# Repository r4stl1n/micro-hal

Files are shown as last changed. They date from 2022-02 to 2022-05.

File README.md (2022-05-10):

# Micro Hal - Spot Micro bot Variation

Notice: The current GO rewrite is paused while we iron out the hardware and electornic selection and support.
For the time being ros-noetic will be used. Please check the ros-rework branch.

This take on the spot-micro attempts to pull pieces together from various different spot projects into one complete package.

The goal of this project is to not only pull the best pieces from the various spot projects but also to have a single repo that contains everything you need to get up and running smoothly.

Each project that pieces are taken from will be documented in this README so anyone who is interested can visit the parent projects.

All current code samples, models, and rewrites used for this project will be posted within this repo.

Note: This is a in-progress working spot micro bot written in GO

## Project Structure

Due to the amount of different data involved the project will be stored in various directories. This goes as follows:

```bash
micro-hal
├── code                       - Code repository for working with micro hal
│   ├── cmd                    - Micro hal Applications
│   │    └── hal-utilities     - Utility Application
│   │
├── parts                      - Parts Necessary
│    └── 3d-prints             
│       ├── freecad            - Original Free Cad Files
│       └── stl                - 3d Printable STL Files
│           └── templates      - Template STLS to modify for different hardware
│
└── sim                        - Sim folder containing everything required to run in gazebo
    ├── meshes                 
    │   └── stl                - STL files used to render the bot in gazebo
    ├── plugin                 - Gazebo plugin source directory
    │   └── include
    ├── urdf                   - The urdf and xacro file for the micro-hal bot
    └── world                  - Folder containing the world defenition file for gazebo

```

## Reference && Community

Deok-Yeon Kim (KDY0523) - Original design of the sport micro: https://www.thingiverse.com/thing:3445283

Michael Kubina (michaelkubina) - Easy print redesign of the spot micro: https://github.com/michaelkubina/SpotMicroESP32/

CHVMP - Original quad kinematics and node code - https://github.com/chvmp/champ

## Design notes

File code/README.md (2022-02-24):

# Code

This is the central area for code that is used to work with and to control the Micro-Hal bot.
Below is a break down of the current features and components that work within the micro-hal framework.

TODO: Fill in the NATS/MSGPack based singaling 

## Requirements

The solution uses a make file to build the project and to ensure code formatting and checking.

StaticCheck will need to be installed this can be done by calling

```bash
go install honnef.co/go/tools/cmd/staticcheck@latest
```

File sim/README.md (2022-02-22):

# Sim

This folder contains everything needed to run micro-hal in simulation using gazebo.

TODO: Fill this out alot better

## Setup

Below are the rough steps for getting the simulation running

### Building the micro-hal plugin
In order for our simulation to work and be able to communicate with the micro-hal stack we first have to build our plugin so it can work.
Aside from needing the gazebo-dev libraries we will also needs a nats and msgpack library

TODO: Add the lib names here for debian

To build the project simply do the following.

```bash
cd plugin
mkdir build
cd build
cmake ../
make
```

### Exporting the plugin path

In order for gazebo to be able to find our plugin we need to export the plugin location. In a terminal do the following

```bash
export GAZEBO_PLUGIN_PATH=${GAZEBO_PLUGIN_PATH}:<Full Path to the cmake-build-debug>
```

### GZServer
To start the gzserver context with our selected world do the following.

```bash
export GAZEBO_PLUGIN_PATH=${GAZEBO_PLUGIN_PATH}:<Full Path to the cmake-build-debug>
gzserver world/hal.world --verbose
```

### GZClient
To start the client run the following

```bash
export GAZEBO_PLUGIN_PATH=${GAZEBO_PLUGIN_PATH}:<Full Path to the cmake-build-debug>
gzclient --verbose

```

### Spawn robot
Finally all that is left is to spawn our robot. Gazebo can load a urdf file directly so no need to convert it over to a sdf

```bash
export GAZEBO_PLUGIN_PATH=${GAZEBO_PLUGIN_PATH}:<Full Path to the cmake-build-debug>
gz model --spawn-file=./urdf/micro-hal.urdf --model-name=micro-hal
```

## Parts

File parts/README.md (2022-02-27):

# Parts

Here are the things you will need to purchase in order to build the bot the same way that is described in this repo. 
The table here will all be amazon (none affiliate) links however feel free to source the parts from wherever you want.
Going to assume you have all the side things need (Soldering Iron, Flux, Printer Filament, Wires,Etc) 

Note: The amount specifies how many of a single component you need. Ex. the Ultrasonic sensors ship in packs of 5. We only need 2 of those 5 for the build.

If you are looking for the 3d Printed Parts just navigate to the 3d-prints folder.

## The Damage

While the spot micro bots are "affordable" compared to the real spot bot they are still costly. With just whats listed here the total is the following.

Total: **$447**

This does not include filament, wires, or anything else.

## Electronics

The electronics necessary in order to build the hal bot

| Name |Usage | Amount | Cost | Link |
|---| ---| ---|---|---|
| Raspberry Pi 4 B 8GB | Processing | 1  | $55 | [Link](https://www.adafruit.com/product/4296) |
| 19m 12V Push Button | On/Off Button | 1  | $17 | [Link](https://www.amazon.com/dp/B08225LGRT) | 
| 200W 15A DC-DC Power Supply | Voltage Regulator (Servo) | 1  | $15 | [Link](https://www.amazon.com/dp/B072BN43P8) | 
| DS3218MG 20KG Digital Servo High | Leg Movement | 12 | $204| [Link](https://www.amazon.com/dp/B076CNKQX4) |
| PCA9685 16 Channel PWM Server Driver  | Servo Control | 1  | $10 | [Link](https://www.amazon.com/dp/B014KTSMLA) |
| SSD1306 Driver I2C Display | Status Display | 1  | $7  | [Link](https://www.amazon.com/dp/B072Q2X2LL) |
| Zeee 7.4V 2S 5200mAh Lipo Battery 50C | Power Source | 1  | $35 | [Link](https://www.amazon.com/dp/B08DD38XKV) |
| LSM6DS3 Module 6 degress IMU | Orientation / Balance | 1  | $9  | [Link](https://www.amazon.com/dp/B091TPT3TJ) |
| HC-SR04 Ultrasonic Sensor Module | Collision Avoidance | 2  | $8  | [Link](https://www.amazon.com/dp/B07R7RMXTY) |
| iFlight Mirco BEC 5V 3A / 12V 2A | Voltage Regulator (RPi) | 1  | $15 | [Link](https://www.amazon.com/dp/B0823QLMWC) | 
| Servo Extension Cord Cable | Extend Servo Wires | 12 | $8  | [Link](https://www.amazon.com/dp/B01LA9YDEI) |

## Hardware

The hardware necessary to put it all together

| Name | Amount | Cost | Link |
|---| ---| ---|---|
| 625ZZ Bearing | 8 | $11 | [Link](https://www.amazon.com/dp/B081YRKRNS) |
| M2x0.4mm Hex Nuts | 84  | $9  | [Link](https://www.amazon.com/dp/B07H3SXSN2) |
| M2x8 Socket Hex Pan | 84  | $9  | [Link](https://www.amazon.com/dp/B01EZPNXZO) |
| M3 Carbon Steel Hex Nuts | 144 | $14 | [Link](https://www.amazon.com/dp/B07H3SXSN2) |
| M3 x 8mm Socket Head Cap Screws | 80  | $9  | [Link](https://www.amazon.com/dp/B07NTG92SL) |
| M3x20mm Screw Cap Point Hex | 64  | $11 | [Link](https://www.amazon.com/dp/B0143GZHDG) |

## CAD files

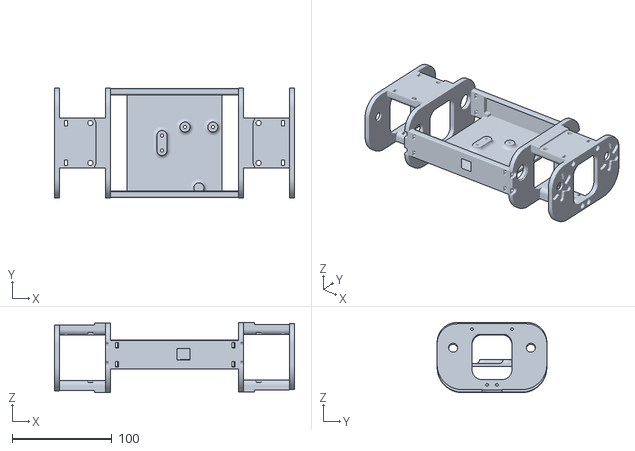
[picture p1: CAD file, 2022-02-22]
sim/meshes/stl/mainbody.stl
240.7 x 110.0 x 70.4

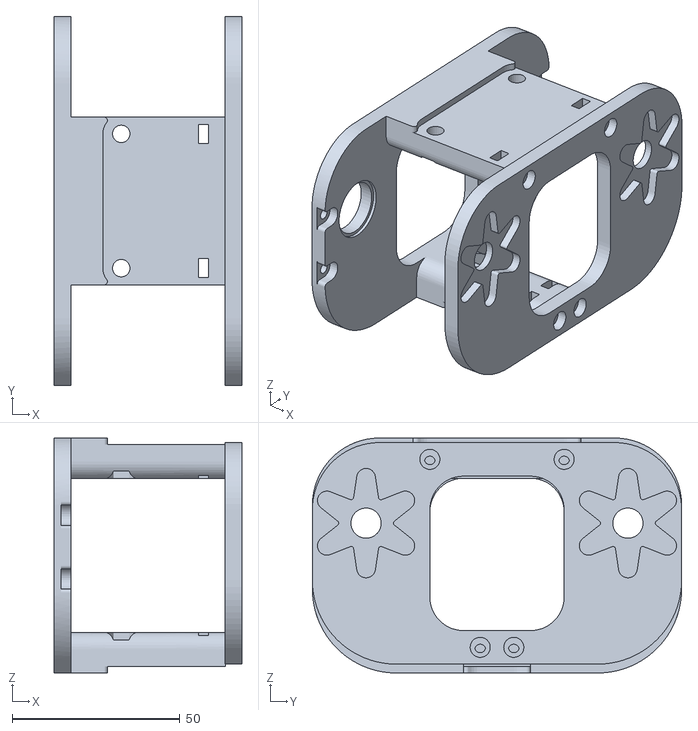
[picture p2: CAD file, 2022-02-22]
sim/meshes/stl/rearmain.stl
55.9 x 110.0 x 70.0

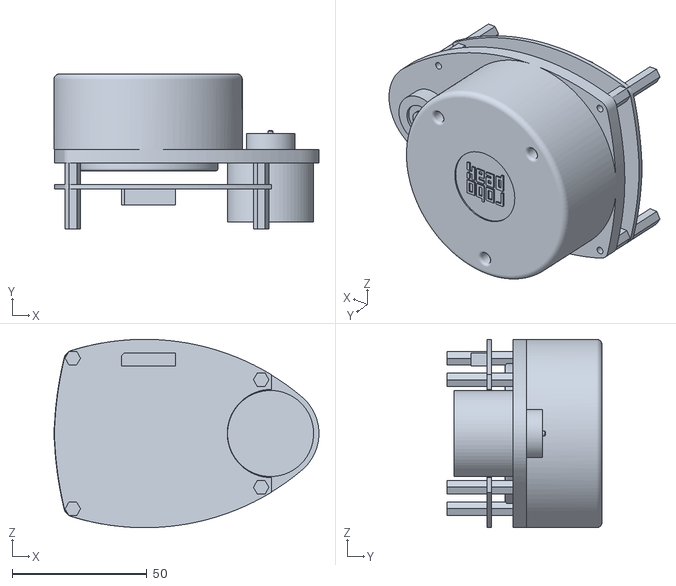
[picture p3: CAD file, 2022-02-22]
sim/meshes/stl/rplidar_main.STL
98.5 x 57.7 x 70.0

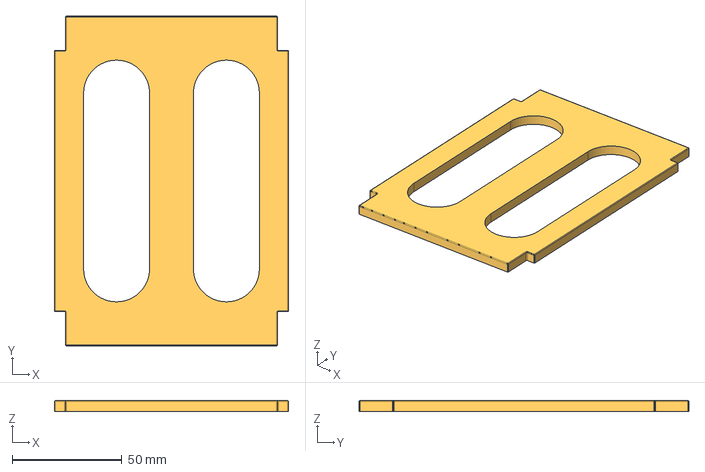
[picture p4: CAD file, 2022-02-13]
parts/3d-prints/freecad/Circuitboard_Mount (Template).FCStd
106.5 x 150.0 x 5.00 mm

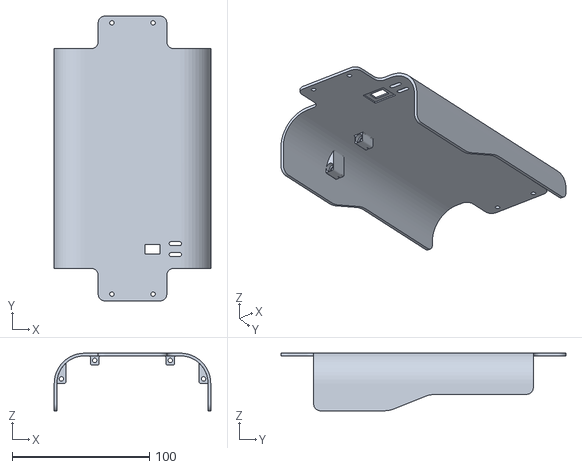
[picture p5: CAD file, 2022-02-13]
parts/3d-prints/stl/templates/Top_Cover (Template).stl
114.0 x 207.5 x 42.0

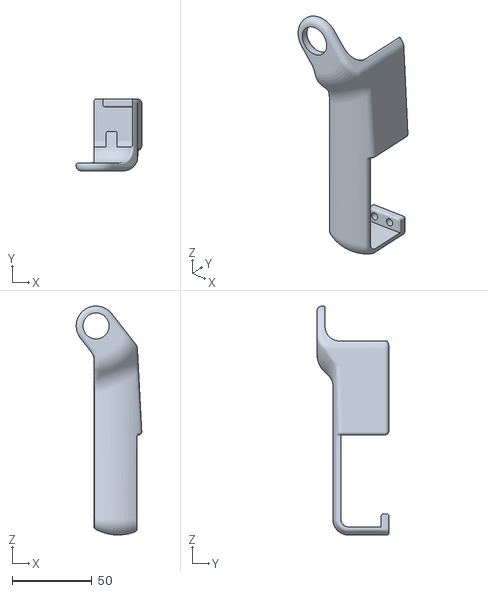
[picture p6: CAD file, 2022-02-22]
sim/meshes/stl/R_arm_cover.stl
41.2 x 45.0 x 143.5

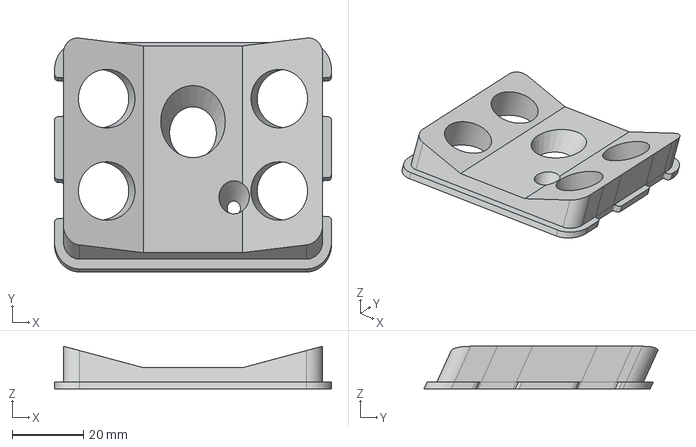
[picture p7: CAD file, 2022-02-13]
parts/3d-prints/freecad/sensormount_esp32_cam.FCStd
78.0 x 65.9 x 12.0 mm

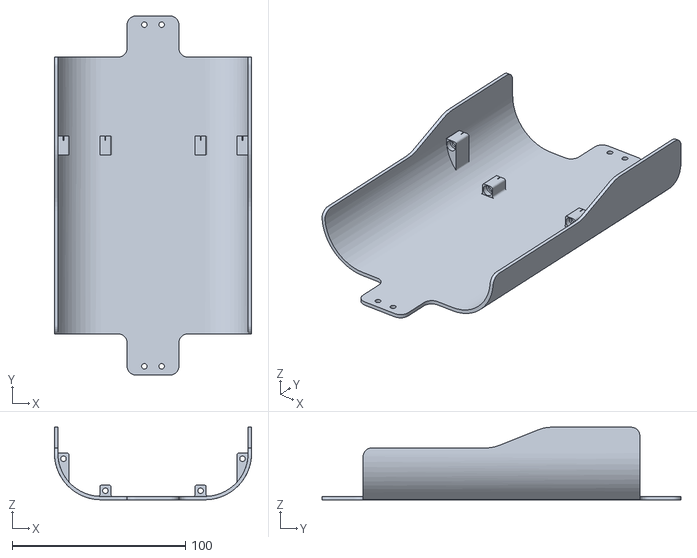
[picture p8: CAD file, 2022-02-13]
parts/3d-prints/stl/templates/Bottom_Cover (Template).stl
114.0 x 207.5 x 42.0

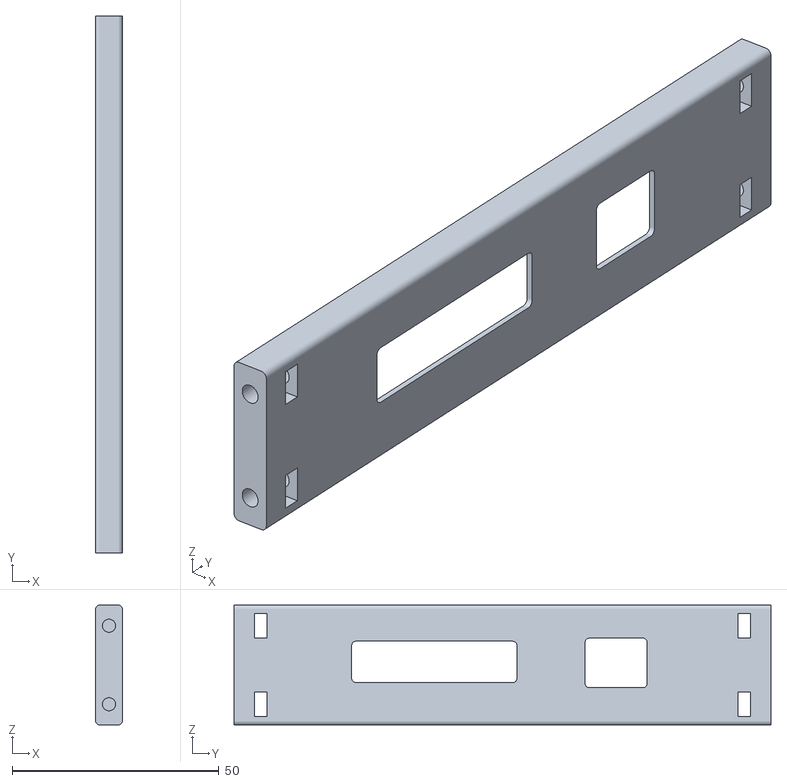
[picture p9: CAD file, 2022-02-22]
sim/meshes/stl/jetson_sidepart.stl
6.50 x 130.0 x 29.0

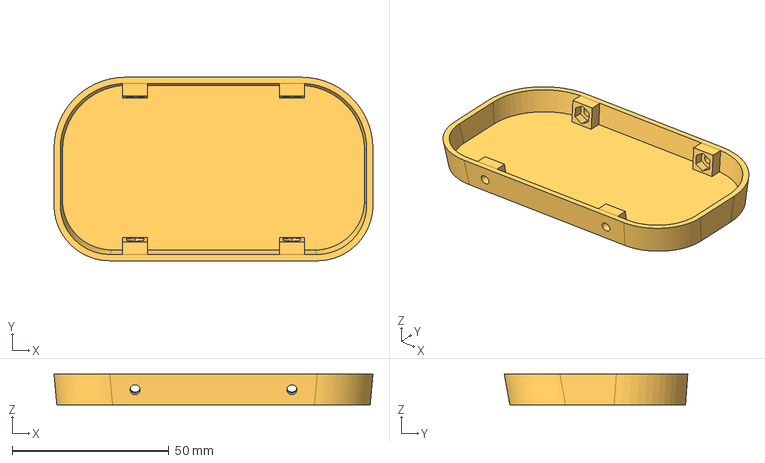
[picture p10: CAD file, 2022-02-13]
parts/3d-prints/freecad/Rear_Cover_Plate_Template.FCStd
101.7 x 58.5 x 9.75 mm

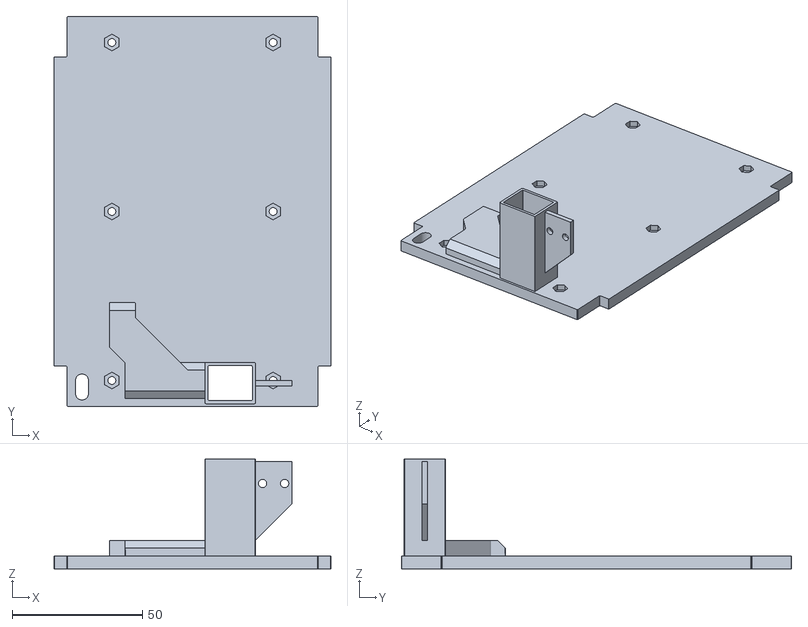
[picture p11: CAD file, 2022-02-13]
parts/3d-prints/stl/templates/Circuitry_Mountingplate (Template).stl
106.5 x 150.0 x 42.2

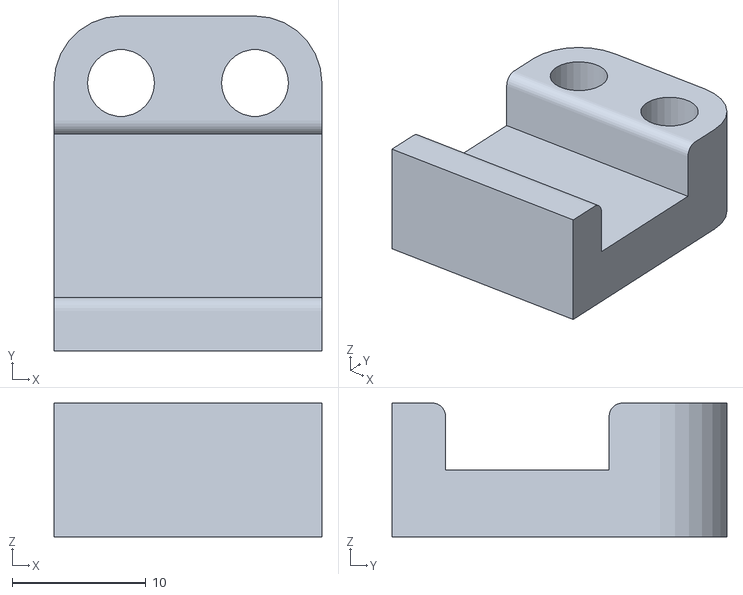
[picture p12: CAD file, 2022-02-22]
sim/meshes/stl/testmount.stl
20.0 x 25.0 x 10.0

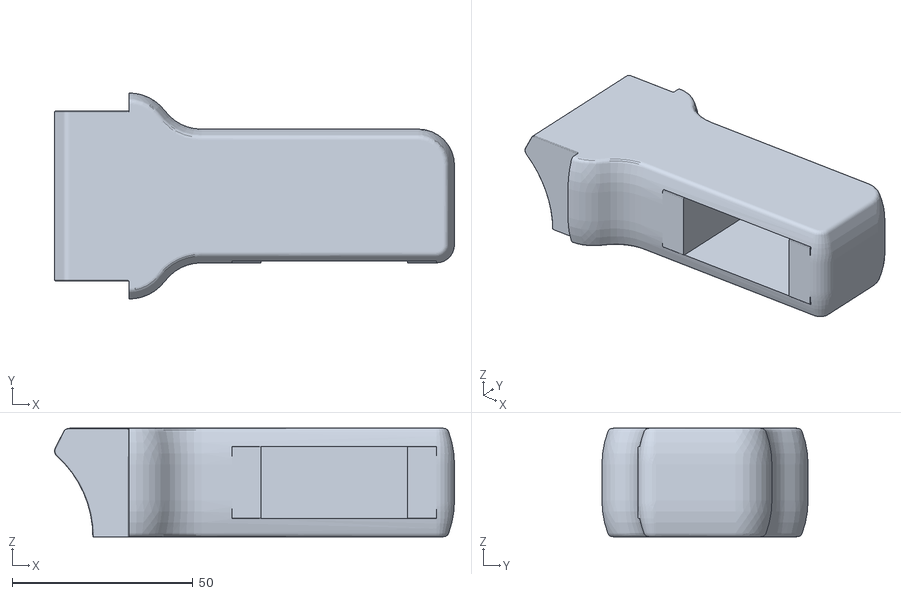
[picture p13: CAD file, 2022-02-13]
parts/3d-prints/stl/templates/Limb_Basebody (Template).stl
110.6 x 57.0 x 30.0

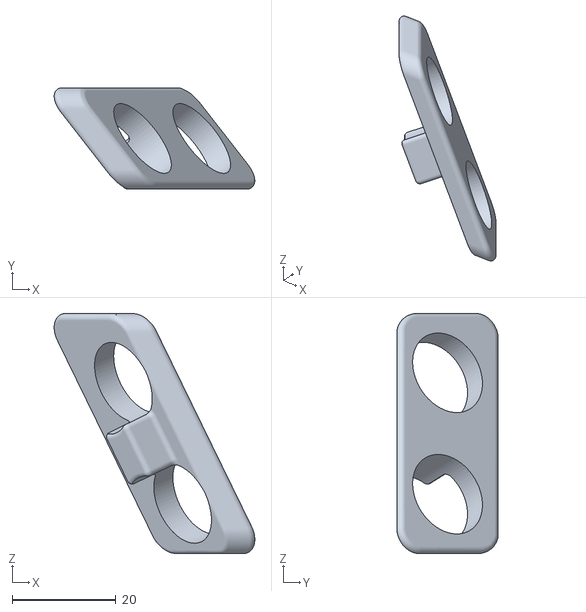
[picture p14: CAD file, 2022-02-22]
sim/meshes/stl/L_ultra_sonic.stl
38.6 x 19.5 x 46.2

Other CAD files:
parts/3d-prints/freecad/Sensormount.FCStd
parts/3d-prints/freecad/Front_Cover.FCStd
parts/3d-prints/stl/templates/Rear_Cover (Template).stl
sim/meshes/stl/ledholder.stl
parts/3d-prints/freecad/Bottom_Cover (Template).FCStd
parts/3d-prints/freecad/Bottom_Cover_Split_Front.FCStd
parts/3d-prints/freecad/Bottom_Cover_Split_Rear.FCStd
parts/3d-prints/freecad/Bottom_Shoulder.FCStd
parts/3d-prints/freecad/Cameramount.FCStd
parts/3d-prints/freecad/Chassis_Side.FCStd
parts/3d-prints/freecad/Circuitry_Mountingplate (Template).FCStd
parts/3d-prints/freecad/Circuitry_Mountingplate.FCStd
parts/3d-prints/freecad/Circuitry_Mountingplate_Extended.FCStd
parts/3d-prints/freecad/Circuitry_Mountingplate_SZBK07.FCStd
parts/3d-prints/freecad/Circuitry_Mountingplate_SZBK07_Extended.FCStd
parts/3d-prints/freecad/Foot_Tip.FCStd
parts/3d-prints/freecad/Front_Cover_Optimized.FCStd
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

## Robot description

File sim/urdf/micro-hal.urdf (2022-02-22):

<?xml version="1.0" encoding="utf-8"?>
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
<robot name="Micro-Hal">
  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
  <link name="base_link"/>
  <link name="base_inertia">
    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
    <inertial>
      <mass value="2.80"/>
      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
    </inertial>
  </link>
  <joint name="base_inertia_joint" type="fixed">
    <parent link="base_link"/>
    <child link="base_inertia"/>
  </joint>
  <link name="rear_link">
    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
    <inertial>
      <mass value="0.20"/>
      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
    </inertial>
  </link>
  <joint name="base_rear" type="fixed">
    <parent link="base_link"/>
    <child link="rear_link"/>
  </joint>
  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
  <link name="front_link">
    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
    <inertial>
      <mass value="0.20"/>
      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
    </inertial>
  </link>
  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
  <joint name="base_front" type="fixed">
    <parent link="base_link"/>
    <child link="front_link"/>
  </joint>
  <link name="front_left_shoulder_link">
    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
    <inertial>
      <mass value="0.10"/>
      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
    </inertial>
  </link>
  <link name="front_left_leg_link_cover">
    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
  </link>
  <link name="front_left_leg_link">
    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
    <inertial>
      <mass value="0.15"/>
      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
    </inertial>
  </link>
  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
  <link name="front_left_foot_link">
    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
    <inertial>
      <mass value="0.1"/>
      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
    </inertial>
  </link>
  <link name="front_left_toe_link">
    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
    <inertial>
      <mass value="0.05"/>
      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
    </inertial>
  </link>
  <joint name="front_left_shoulder" type="revolute">
    <parent link="base_link"/>
    <child link="front_left_shoulder_link"/>
    <axis xyz="1 0 0"/>
    <origin rpy="0 0 0" xyz="0.093 0.0395 0"/>
    <limit effort="1000.0" lower="-0.548" upper="0.548" velocity="0.7"/>
    <dynamics damping="0.0" friction="0.5"/>
  </joint>
  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
  <joint name="front_left_leg" type="revolute">
    <parent link="front_left_shoulder_link"/>
    <child link="front_left_leg_link"/>
    <axis xyz="0 1 0"/>
    <origin rpy="0 0 0" xyz="0 0.055 0"/>
    <limit effort="1000.0" lower="-2.666" upper="1.548" velocity="0.5"/>
    <dynamics damping="0.0" friction="0.0"/>
  </joint>
  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
  <joint name="front_left_leg_cover_joint" type="fixed">
    <parent link="front_left_leg_link"/>
    <child link="front_left_leg_link_cover"/>
    <origin xyz="0 0 0"/>
  </joint>
  <joint name="front_left_foot" type="revolute">
    <parent link="front_left_leg_link"/>
    <child link="front_left_foot_link"/>
    <axis xyz="0 1 0"/>
    <origin rpy="0 0 0" xyz="0.014 0 -0.109"/>
    <limit effort="1000.0" lower="-2.59" upper="0.1" velocity="0.5"/>
    <dynamics damping="0.0" friction="0.5"/>
  </joint>
  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
  <joint name="front_left_toe" type="fixed">
    <parent link="front_left_foot_link"/>
    <child link="front_left_toe_link"/>
    <origin xyz="0 0 -0.13"/>
  </joint>
  <link name="front_right_shoulder_link">
    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
    <inertial>
      <mass value="0.10"/>
      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
    </inertial>
  </link>
  <link name="front_right_leg_link_cover">
    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
  </link>
  <link name="front_right_leg_link">
    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
    <inertial>
      <mass value="0.15"/>
      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
    </inertial>
  </link>
  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
  <link name="front_right_foot_link">
    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
    <inertial>
      <mass value="0.1"/>
      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
    </inertial>
  </link>
  <link name="front_right_toe_link">
    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
    <inertial>
      <mass value="0.05"/>
      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
    </inertial>
  </link>
  <joint name="front_right_shoulder" type="revolute">
    <parent link="base_link"/>
    <child link="front_right_shoulder_link"/>
    <axis xyz="1 0 0"/>
    <origin rpy="0 0 0" xyz="0.093 -0.0395 0"/>
    <limit effort="1000.0" lower="-0.548" upper="0.548" velocity="0.7"/>
    <dynamics damping="0.0" friction="0.5"/>
  </joint>
  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
  <joint name="front_right_leg" type="revolute">
    <parent link="front_right_shoulder_link"/>
    <child link="front_right_leg_link"/>
    <axis xyz="0 1 0"/>
    <origin rpy="0 0 0" xyz="0 -0.055 0"/>
    <limit effort="1000.0" lower="-2.666" upper="1.548" velocity="0.5"/>
    <dynamics damping="0.0" friction="0.0"/>
  </joint>
  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
  <joint name="front_right_leg_cover_joint" type="fixed">
    <parent link="front_right_leg_link"/>
    <child link="front_right_leg_link_cover"/>
    <origin xyz="0 0 0"/>
  </joint>
  <joint name="front_right_foot" type="revolute">
    <parent link="front_right_leg_link"/>
    <child link="front_right_foot_link"/>
    <axis xyz="0 1 0"/>
    <origin rpy="0 0 0" xyz="0.014 0 -0.109"/>
    <limit effort="1000.0" lower="-2.59" upper="0.1" velocity="0.5"/>
    <dynamics damping="0.0" friction="0.5"/>
  </joint>
  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
  <joint name="front_right_toe" type="fixed">
    <parent link="front_right_foot_link"/>
    <child link="front_right_toe_link"/>
    <origin xyz="0 0 -0.13"/>
  </joint>
  <link name="rear_left_shoulder_link">
    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
    <inertial>
      <mass value="0.10"/>
      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
    </inertial>
  </link>
  <link name="rear_left_leg_link_cover">
    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
  </link>
  <link name="rear_left_leg_link">
    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
    <inertial>
      <mass value="0.15"/>
      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
    </inertial>
  </link>
  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
  <link name="rear_left_foot_link">
    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
    <inertial>
      <mass value="0.1"/>
      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
    </inertial>
  </link>
  <link name="rear_left_toe_link">
    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
    <inertial>
      <mass value="0.05"/>
      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
    </inertial>
  </link>
  <joint name="rear_left_shoulder" type="revolute">
    <parent link="base_link"/>
    <child link="rear_left_shoulder_link"/>
    <axis xyz="1 0 0"/>
    <origin rpy="0 0 0" xyz="-0.093 0.0395 0"/>
    <limit effort="1000.0" lower="-0.548" upper="0.548" velocity="0.7"/>
    <dynamics damping="0.0" friction="0.5"/>
  </joint>
  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
  <joint name="rear_left_leg" type="revolute">
    <parent link="rear_left_shoulder_link"/>
    <child link="rear_left_leg_link"/>
    <axis xyz="0 1 0"/>
    <origin rpy="0 0 0" xyz="0 0.055 0"/>
    <limit effort="1000.0" lower="-2.666" upper="1.548" velocity="0.5"/>
    <dynamics damping="0.0" friction="0.0"/>
  </joint>
  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
  <joint name="rear_left_leg_cover_joint" type="fixed">
    <parent link="rear_left_leg_link"/>
    <child link="rear_left_leg_link_cover"/>
    <origin xyz="0 0 0"/>
  </joint>
  <joint name="rear_left_foot" type="revolute">
    <parent link="rear_left_leg_link"/>
    <child link="rear_left_foot_link"/>
    <axis xyz="0 1 0"/>
    <origin rpy="0 0 0" xyz="0.014 0 -0.109"/>
    <limit effort="1000.0" lower="-2.59" upper="0.1" velocity="0.5"/>
    <dynamics damping="0.0" friction="0.5"/>
  </joint>
  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
  <joint name="rear_left_toe" type="fixed">
    <parent link="rear_left_foot_link"/>
    <child link="rear_left_toe_link"/>
    <origin xyz="0 0 -0.13"/>
  </joint>
  <link name="rear_right_shoulder_link">
    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
    <inertial>
      <mass value="0.10"/>
      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
    </inertial>
  </link>
  <link name="rear_right_leg_link_cover">
    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
  </link>
  <link name="rear_right_leg_link">
    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
    <inertial>
      <mass value="0.15"/>
      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
    </inertial>
  </link>
  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
  <link name="rear_right_foot_link">
    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
    <inertial>
      <mass value="0.1"/>
      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
    </inertial>
  </link>
  <link name="rear_right_toe_link">
    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
    <inertial>
      <mass value="0.05"/>
      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
    </inertial>
  </link>
  <joint name="rear_right_shoulder" type="revolute">
    <parent link="base_link"/>
    <child link="rear_right_shoulder_link"/>
    <axis xyz="1 0 0"/>
    <origin rpy="0 0 0" xyz="-0.093 -0.0395 0"/>
    <limit effort="1000.0" lower="-0.548" upper="0.548" velocity="0.7"/>
    <dynamics damping="0.0" friction="0.5"/>
  </joint>
  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
  <joint name="rear_right_leg" type="revolute">
    <parent link="rear_right_shoulder_link"/>
    <child link="rear_right_leg_link"/>
    <axis xyz="0 1 0"/>
    <origin rpy="0 0 0" xyz="0 -0.055 0"/>
    <limit effort="1000.0" lower="-2.666" upper="1.548" velocity="0.5"/>
    <dynamics damping="0.0" friction="0.0"/>
  </joint>
  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
  <joint name="rear_right_leg_cover_joint" type="fixed">
    <parent link="rear_right_leg_link"/>
    <child link="rear_right_leg_link_cover"/>
    <origin xyz="0 0 0"/>
  </joint>
  <joint name="rear_right_foot" type="revolute">
    <parent link="rear_right_leg_link"/>
    <child link="rear_right_foot_link"/>
    <axis xyz="0 1 0"/>
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

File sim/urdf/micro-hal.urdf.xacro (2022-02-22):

<?xml version="1.0" encoding="UTF-8"?>
<robot xmlns:xacro="http://www.ros.org/wiki/xacro" name="Micro-Hal">
   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
   <xacro:property name="body_length" value="0.140" />
   <xacro:property name="body_width" value="0.110" />
   <xacro:property name="body_height" value="0.070" />
   <xacro:property name="lidar_length" value="0.0985" />
   <xacro:property name="lidar_width" value="0.0577" />
   <xacro:property name="lidar_height" value="0.070" />
   <xacro:property name="front_length" value="0.058" />
   <xacro:property name="rear_length" value="0.040" />
   <xacro:property name="shoulder_length" value="0.044" />
   <xacro:property name="shoulder_width" value="0.038" />
   <xacro:property name="leg_length" value="0.109" />
   <xacro:property name="foot_length" value="0.13" />
   <xacro:property name="toe_radius" value="0.020" />
   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
   <xacro:property name="toe_width" value="0.020" />
   <xacro:property name="shift" value="0.055" />
   <xacro:property name="shiftx" value="0.093" />
   <xacro:property name="shifty" value="0.0395" />
   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
   <xacro:macro name="gen_shoulder" params="name left">
      <link name="${name}">
         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
         <inertial>
            <mass value="0.10" />
            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
         </inertial>
      </link>
   </xacro:macro>
   <xacro:macro name="gen_shoulder_joint" params="pos shiftx shifty">
      <joint name="${pos}_shoulder" type="revolute">
         <parent link="base_link" />
         <child link="${pos}_shoulder_link" />
         <axis xyz="1 0 0" />
         <origin rpy="0 0 0" xyz="${shiftx} ${shifty} 0" />
         <limit effort="1000.0" velocity="0.7" lower="-0.548" upper="0.548"/>
         <dynamics damping="0.0" friction="0.5" />
      </joint>
      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
   </xacro:macro>
   <xacro:macro name="gen_leg" params="name left">
      <link name="${name}_cover">
         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
      </link>
      <link name="${name}">
         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
         <inertial>
            <mass value="0.15" />
            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
         </inertial>
      </link>
      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
   </xacro:macro>
   <xacro:macro name="gen_leg_joint" params="pos shift">
      <joint name="${pos}_leg" type="revolute">
         <parent link="${pos}_shoulder_link" />
         <child link="${pos}_leg_link" />
         <axis xyz="0 1 0" />
         <origin rpy="0 0 0" xyz="0 ${shift} 0" />
         <limit effort="1000.0" velocity="0.5" lower="-2.666" upper="1.548"/>
         <dynamics damping="0.0" friction="0.0" />
      </joint>
      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
      <joint name="${pos}_leg_cover_joint" type="fixed">
         <parent link="${pos}_leg_link" />
         <child link="${pos}_leg_link_cover" />
         <origin xyz="0 0 0" />
      </joint>
   </xacro:macro>
   <xacro:macro name="gen_foot" params="name left">
      <link name="${name}">
         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
         <inertial>
            <mass value="0.1" />
            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
         </inertial>
      </link>
   </xacro:macro>
   <xacro:macro name="gen_foot_joint" params="pos">
      <joint name="${pos}_foot" type="revolute">
         <parent link="${pos}_leg_link" />
         <child link="${pos}_foot_link" />
         <axis xyz="0 1 0" />
         <origin rpy="0 0 0" xyz="0.014 0 -${leg_length}" />
         <limit effort="1000.0" velocity="0.5" lower="-2.59" upper="0.1"/>
         <dynamics damping="0.0" friction="0.5" />
      </joint>
      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
   </xacro:macro>
   <xacro:macro name="gen_toe" params="name">
      <link name="${name}">
         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
         <inertial>
            <mass value="0.05" />
            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
         </inertial>
      </link>
   </xacro:macro>
   <xacro:macro name="gen_toe_joint" params="pos">
      <joint name="${pos}_toe" type="fixed">
         <parent link="${pos}_foot_link" />
         <child link="${pos}_toe_link" />
         <origin xyz="0 0 -${foot_length}" />
      </joint>
   </xacro:macro>
   <xacro:macro name="gen_full_leg_joint" params="pos shiftx shifty shift left">
      <xacro:gen_shoulder name="${pos}_shoulder_link" left="${left}" />
      <xacro:gen_leg name="${pos}_leg_link" left="${left}" />
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

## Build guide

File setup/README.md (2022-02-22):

# Setup

This will contain a hopeful step by step guide to preparing and setting up all the software and hardware.

TODO: Implement all of it

[Raspberry Pi Setup](https://github.com/R4stl1n/micro-hal/blob/main/setup/pi.md)

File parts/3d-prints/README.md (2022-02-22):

# 3D Printed Parts
These are the 3d printed parts you will need in order to construct the spot-micro-hal bot.  This is a condensed table list excluding pictures to allow for a easy print of the page to check mark things as you move forward. 

Any files that Have been personally modified cad files will be inside the fusion-files directory

Note: Since this project does not use the esp32 we have omitted the esp32 specific parts and replaced them with custom or the none esp32 parts.

If you would like to see the original list you can find that at:  [Original Repo](https://github.com/michaelkubina/SpotMicroESP32)

At this time i also suggest using the assembly guide found at: [Original Assembly](https://github.com/michaelkubina/SpotMicroESP32/tree/master/assembly)

### Chassis

| Name | normal copies | mirrored copies | total amount | infill | total weight |
|---|---|---|---|---|---|
| Inner Shoulder					| 2 | - | 2 |  20% |  32g |
| Outer Shoulder					| 2 | - | 2 |  20% |  32g |
| Chassis Side						| 2 | - | 2 |  20% |  22g |
| Top Shoulder						| 2 | - | 2 |  20% |  20g |
| Bottom Shoulder					| 2 | - | 2 |  20% |  12g |
| TTL Counterpiece 			 	| 1 | - | 1 |  20% | 5g |
| Circuitry Mounting Plate 		 	| 1 | - | 1 |  20% |  77g |

### Shoulder Joints 

| Name | normal copies | mirrored copies | total amount | infill | total weight |
|---|---|---|---|---|---|
| Shoulder Joint Servomount	 		| 2 | 2 | 4 |  20% |  48g |
| Shoulder Joint Servohorn Cap		| 4 | - | 4 |  20% |  28g |
| Shoulder Joint Ball Bearing Pin	| 4 | - | 4 |  20% | 4g |

### Leg

| Name | normal copies | mirrored copies | total amount | infill | total weight |
|---|---|---|---|---|---|
| Limb Top Shell					 | 2 | 2 | 4 |  20% |  92g |
| Limb Bottom Shell Thumbnail		 | 2 | 2 | 4 |  20% | 100g |
| Limb Ball Bearing Mount **long**	 | 2 | 2 | 4 |  20% |  20g |
| Limb Servohorn Mount **long**		 | 2 | 2 | 4 |  20% |  20g |
| Wrist							 | 2 | 2 | 4 |  20% | 104g |
| Wrist Counterpiece					| 2 | 2 | 4 |  20% |  36g |
| Shoulder Joint Ball Bearing Pin	 | 4 | - | 4 |  20% | 4g |
| Foot Tip							 | 4 | - | 4 |  20% |  24g |

### Hull

| Name | normal copies | mirrored copies | total amount | infill | total weight |
|---|---|---|---|---|---|
| Front Cover Optimized				 | 1 | - | 1 | 100% |  58g |
| Sensormount 				 | 1 | - | 1 |  20% |  17g |
| Cameramount 			 | 1 | - | 1 |  20% |  15g |
| Rear Cover Shell Longer Version				| 1 | - | 1 | 100% |  40g |
| Rear Cover Plate						 | 1 | - | 1 | 100% |  20g |
| Top Cover Split Front				 | 1 | - | 1 | 100% |  48g |
| Top Cover Split Rear with OLED	 | 1 | - | 1 | 100% |  28g |
| Bottom Cover Split Front			 | 1 | - | 1 | 100% |  46g |
| Bottom Cover Split Rear			 | 1 | - | 1 | 100% |  26g |

### Miscellanious

| Name | normal copies | mirrored copies | total amount | infill | total weight |
|---|---|---|---|---|---|
| Servohorn 6 B-Star				| 12 | - | 12 |  20% |  20g |

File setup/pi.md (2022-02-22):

# Raspberry Pi 4 Model B setup

Here is how we will setup our raspberry pi to work with our current features and setup.

TODO: Clean this up and make it more detailed

## Installation

Using the Raspberry PI Imager flash a copy of ubuntu server.

Run the following commands to install dependencies

```bash
sudo apt-get update
sudo apt-get upgrade

sudo apt-get install build-essential
sudo apt-get install git
sudo apt-get install i2c-tools
sudo apt-get install python-smbus
sudo apt-get install screen

sudo snap install go --classic
```

### Change i2c from root only to work from our user

In order to communicate with our various i2c devices we need to change the i2c group permissions

```bash
sudo groupadd i2c
sudo chown :i2c /dev/i2c-1
sudo chmod g+rw /dev/i2c-1
sudo usermod -aG i2c <YourUserHere>
su root
echo 'KERNEL=="i2c-[0-9]*", GROUP="i2c"' >> /etc/udev/rules.d/10-local_i2c_group.rules
sudo reboot now
```

Once logged in we can verify it all works by doing

```bash
i2cdetect -y 1
```

## Advanced Configuration

These changes are designed to be ran on startup rather than modifying the boot config patterns

### Enable additional i2c ports

In order to connect all our devices we need to expand the i2c ports. We could have all our ports inline with one another and reference them by address that way.
But i found it easier to just enable the extra ports we need.

To do this we need to modify the /boot/firmware/usercfg.txt to include new dtoverlays to turn specific gpio pins on the pi to I2C pins.

Open the /boot/firmware/usercfg.txt using nano

```bash
sudo nano /boot/firmware/usercfg.txt
```

Now we are just going to enable the additional i2c pins we need for the MPU6050 and the SSD1306 we use the original i2c pins to power the PCA9685
Add the following lines to the bottom of the usercfg.txt

```bash
dtoverlay=i2c5
dtoverlay=i2c6
```

Then hit Ctrl+O and then Ctrl+X

What this will do is now enable i2c on the following raspberry pi ports

SDA5 = 32
SCL5 = 33

SDA6 = 15
SCL6 = 16

Now just reboot and the new i2c ports should be avalible

### Setup nats-server

We use nats to transfer messages from the micro-hal components in order to do this all fromt he pi we need to install nats-server and configure it to start on boot up

First we download the latest release for nats-server (As of writing its v2.7.2)

```bash
wget https://github.com/nats-io/nats-server/releases/download/v2.7.2/nats-server-v2.7.2-arm64.deb
```

Then we want to install it using the following

```bash
sudo dpkg -i nats-server-v2.7.2-arm64.deb
```

Once that is done we can use crontab to enter our startup script. We use screen so we can watch our messages go through if needed.
If crontab asks you what your default editor should be select nano if you are unsure.

```bash
crontab -e
```

Now that it is open add this line to the end of it.

```bash
@reboot screen -d -m -S nats-server /usr/local/bin/nats-server
```

If you used nano simply press Ctrl+O and then Ctrl+X to save and exit

All we have to do now is reboot and our nats-server should be started on startup. To verify we can run the following command

```bash
screen -ls
```

You should see a string that shows something similar "781.nats-server (Detached)"

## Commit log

2022-02-13 Added initial repo commit
    [Bottom_Cover (Template).FCStd, Bottom_Cover (Template).stl, Bottom_Cover_Split_Front.FCStd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]
2022-02-13 Uploaded build list / part list
    [Bottom_Cover (Template).FCStd, Bottom_Cover (Template).stl, Bottom_Cover_Split_Front.FCStd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]
2022-02-14 Added servo-test scripts
2022-02-19 Added working calibration and move tool
2022-02-19 Added changes to the calibrate and driver
2022-02-20 Renamed servo cli folder
2022-02-21 Added initial sim files, added urdf and start of gazebo plugin
    [B_cover.stl, F_cover.stl, F_cover_orig.stl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]
2022-02-21 Added new mounting plate stl
    [Circuitry_Mounting_Plate.stl, Rear_Cover_Plate_Template.stl]
2022-02-21 Added missing fusion file
    [Circuitry_Mounting_Plate.f3d]
2022-02-22 Added working ssd1306 driver
2022-02-27 Added working lsm6ds3 driver
2022-02-27 Updated the read me to include the latest imu
2022-03-06 Added trajectory-planner and renamed base,join,and leg
2022-03-06 Added leg-controller
2022-03-06 Added odometry
2022-03-07 Added kinematics
2022-03-07 Fixed potential bug in the kinematics code
2022-03-07 Fixed potential bug with quad leg
2022-03-13 Added start of the joints node
    [ServoMap.json]
2022-03-13 Fixed incorrect i2c bus
2022-03-13 Init servo map and fatal on failed start
